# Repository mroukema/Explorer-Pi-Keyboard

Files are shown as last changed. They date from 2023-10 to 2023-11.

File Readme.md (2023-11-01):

# Explorer Pi Keyboard V2

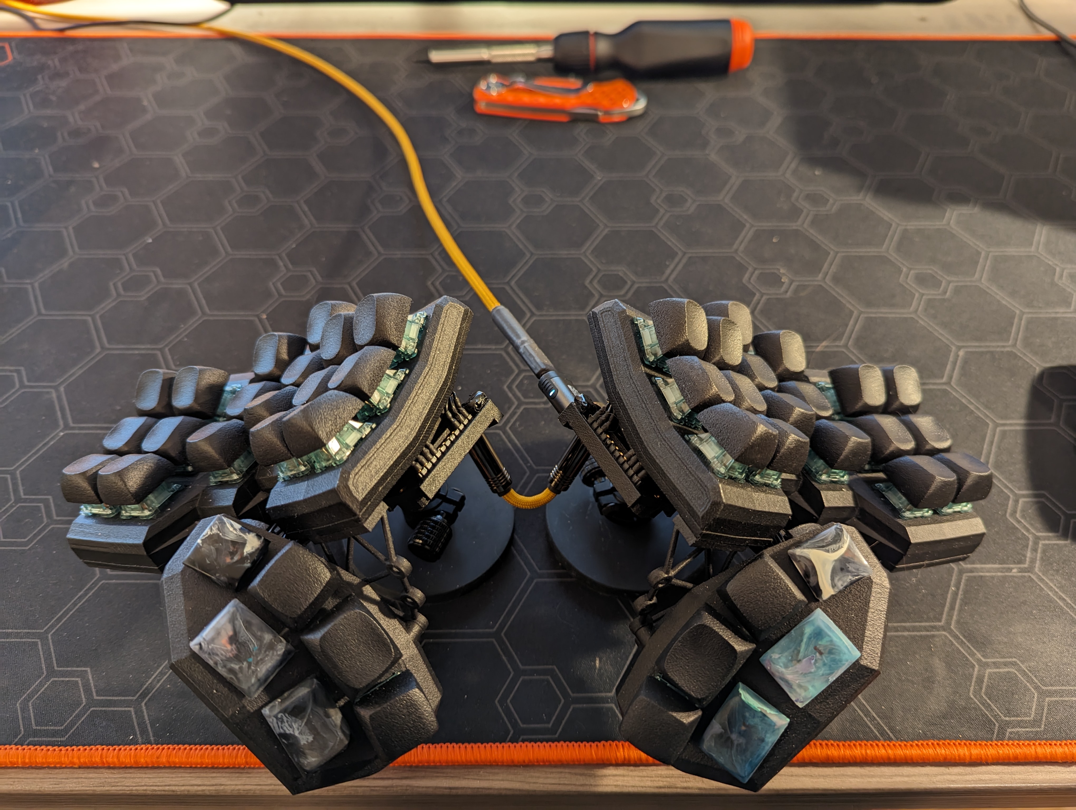
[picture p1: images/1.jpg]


## Introduction 

The Explorer Pi is a customized version of the [Explorer Keyboard RxCT](https://github.com/DreaM117er/Explorer-Keyboard-RxCT/tree/main) designed by [DreaM117er](https://github.com/DreaM117er/). The name comes from the fact that my [original build](https://lemmy.world/post/1733410) of the RxCT was pretty much unmodified aside from using a RP2040 based MCU. 

It's been fitted to my personal ergomomic preferences and some of the originals modualrity has been sacraficed for easier assembly and increased sturdiness. In particular the thumb cluster has been improved with a two piece (top and bottom) design that is much sturdier and has tighter spacing between keys. Additionally any of the thumb cluster keys can be either MX or Choc key switches and this can be changed relatively easily after the fact. 

## Features 
- Thumb cluster with adjustable angles
- MX or choc keyswites an thumb cluster
- Entire thumb cluster is modular (wiring included) and could be easily swapped for a different design
- 1/4" mounting with ARRI locating holes

## Links 

- Explorer PI [QMK Firmware](https://github.com/mroukema/qmk_firmware/tree/explorer_pi_v2/keyboards/explorer_pi/3x6_6) (forked)
- My [Enigma Dual Hot Swap](https://github.com/mroukema/enigma-dual-hs) for thumb cluster keys 
- [Flexible pcb columns](https://skree.us/products/dactyl-compatible-flexible-row-pcbs-populated) by Skree to simplify wiring

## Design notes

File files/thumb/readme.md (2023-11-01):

# Parts
The body of each thumb cluster is made up of a top and bottom half. In addition there is an attachment part to join the thumb cluster to the main keyboard body at an adjustable angle. An optional (but recommended) support strut part is offered in two variation, short and long to further secure the thumb cluster. Finally the mx-spacer is not stictly necessary to use but provides some additional securement for mx keys and a surface to attach pcb to. 

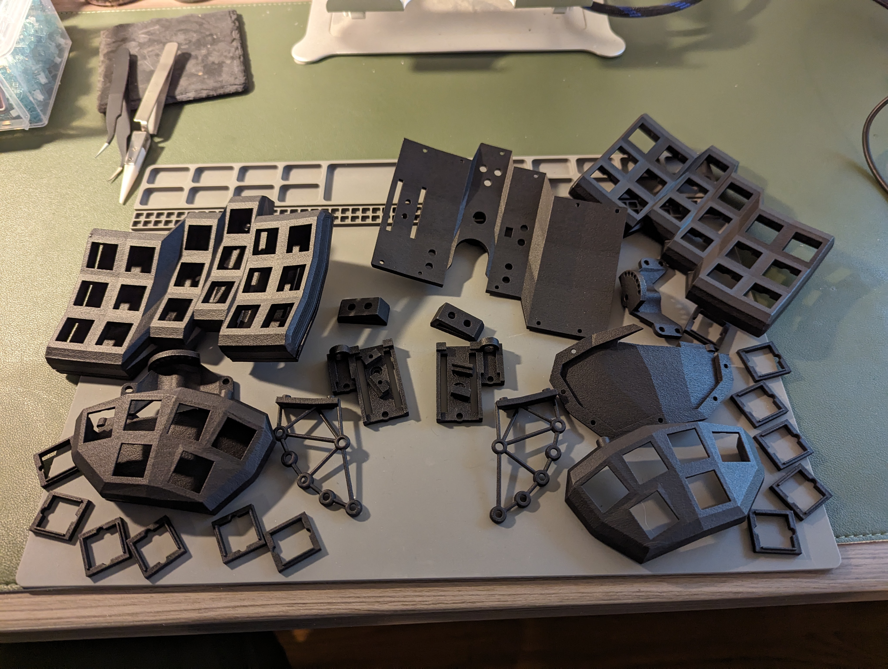
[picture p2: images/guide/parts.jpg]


## Support strut short
Variant of the support sturt compatible with angles between 15-45 degrees.

*note that neither support sturt works with the 0 degree position. As designed the screw position required at 0 degrees overlaps with area where the case meets the top of the strut. 
## Support strut long
Variant of the support sturt compatible with angles between 15-75 degrees.

*note that this still isn't long enough to support the 90 degreee position; it simply seemed to extreme an angle and the part already allows for more rotation than I'll ever use.

## Thumb Attachment 
Part that joins the thumb cluster and main keyboard body together. Allows for angle of attachment to be set between 0-90 degrees in 15 degree increments.

## Thumb Bottom 
Connects to Thumb Attachment via one M2, one M3 screws/threaded insert, and to top via six M2 screws/inserts. Went kinda overboard with threaded attachment points; not all these are sticty needed to be secure, could easily get away with using just three or two. 

## Thumb Top
Connects to Support strut via M3 screws/threaded insert. Switch plate allows for either MX or Choc switches.

Of possible interest might be my [Enigma Dual Hot Swap](https://github.com/mroukema/enigma-dual-hs) single key pcb.

## MX Spacer
Not required but useful for adapting the swich plate height and to provied a surface to glue a pcb to if you wish to be able to hot swap switches with zero disassembly. 

If outsourcing your 3D printing you may find that these end up being priced as the minumum unit cost, meaning you are mostly paying for handing fees not the actual printing. It would be best to batch a bunch of these together by a connecting them with thin bridge and cut them away later. 

TODO: add batched mx spacer file

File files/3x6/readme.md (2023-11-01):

# Parts
The main body of the keyboard is made up of a top and bottom half for each keyboard half. There are two variations on the bottom half explained below; choose one.



## Case Bottom Default
This default version of the bottom half of the case has the 1/4" mounting point in the same position as the V1 model; it's centered on the middle finger column. 

This version also has the holes required to attach both the battery and front mount accessory parts. 

## Case Bottom Offset (still untested)
The offset version of the bottom half of the case has the 1/4" mounting hole shifted down and toward the pinky column. This (hopefully) shifts the center of balance enough to allow for typing without tipping on a ~2.5" dia stand.  

This version does not have any holes for battery of front mount accessory parts. 

## Case Top

Top of case and MX switch plate.

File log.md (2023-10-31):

# Development log

## Updates

- 2023.11.31 adding in bulk all the files that make up my personal V2 of the Explorer keyboard. Changes include 
    - adjusted stagger of each column
    - adjusted splay and height on the pinky columns
    - made the switch plate one piece 
    - added side walls to the switch plate for full enclosure
    - added additional support to the thumb cluster so it has less wobble
    - two piece thumb cluster makes it sturdier and more compact for tighter keyswitch spacing 
    - 6 key thumb cluster
    - support for both choc and mx switches on thumb cluster with swappablity
    - added ARRI locating holes to the 1/4" mounting point
    - added an alternate base plate with modified 1/4" mounting point location for better center of balance
    - reduced total count of required inserts and screws 
    - reduced diameter of the 1/4" insert hole to better fit the inserts I was able to source

## V3/Future potential changes  

- Reduce thickness of trrs mount to for better cable compatabilty 
- fully encluse the mcu 
- move mcu to other side of board
    - trrs should remain on current side, wiring considerations required 
- improve wiring with mating machine pins on top and bottom half
- trackball/trackpoint module
- screen module 
- WiFi based wireless impl
- Reduce MCU assembly part count and improve general design

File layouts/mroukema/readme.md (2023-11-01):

# Layout

Personal layout reference, generated by [Keyboard Layout Editor](http://www.keyboard-layout-editor.com/#/gists/f90687ef3c709af049c13a0a4d5b263d)

Firmware: [Explorer PI QMK Firmware (fork)](https://github.com/mroukema/qmk_firmware/tree/explorer_pi_v2/keyboards/explorer_pi/3x6_6)

## Idle Timeout

Layout features an idle timeout feature that will return the keyboard to the default layer, in this case RSHTD. This will trigger if on any non-default layer and `TIMEOUT_TO_DEFAULT_LAYER` ms have elapsed since last keyboard input. This feature is disabled if `TIMEOUT_TO_DEFAULT_LAYER` is undefined.

```C
#define TIMEOUT_TO_DEFAULT_LAYER 1000 * 60 * 3 // 3mins
```

## Combos

All combos evaluated relative to RSTHD layer regardless of acive layer as a result of below option being used:

```C
#define COMBO_ONLY_FROM_LAYER 0
```

- Alt + C               = TAB
- Alt + S               = ESC
- O + U                 = "OU"
- Q + U                 = "QU"
- Left + Right Shift    = Momentary System Layer
- Num + Sym             = Momentary System Layer
- Swap Hands + Shift    = Momentary System Layer
- Cmd + Minus           = Return to RSTHD Layer
  
## RSTHD (default)

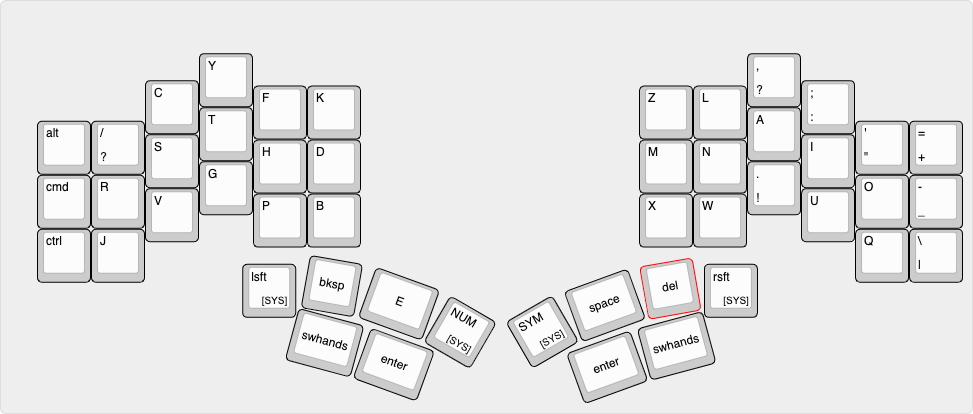
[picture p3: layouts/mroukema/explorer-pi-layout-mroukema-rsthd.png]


## Numpad

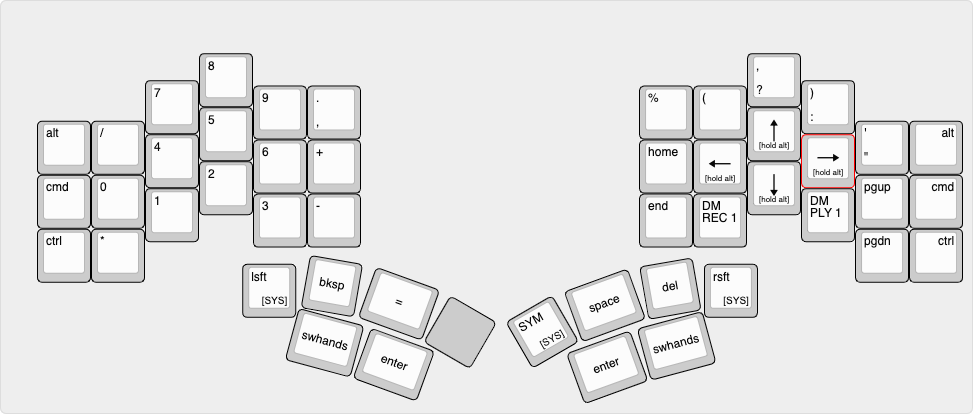
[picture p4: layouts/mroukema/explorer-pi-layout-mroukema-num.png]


## Symbol 

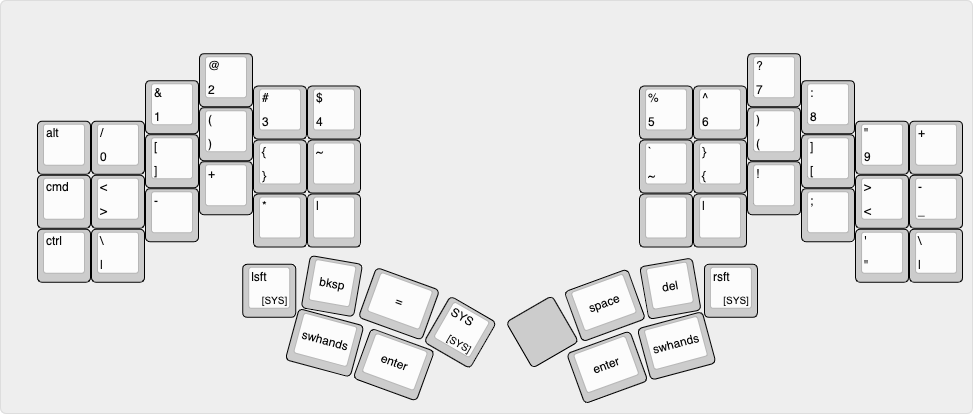
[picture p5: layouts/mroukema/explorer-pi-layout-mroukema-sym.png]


## System

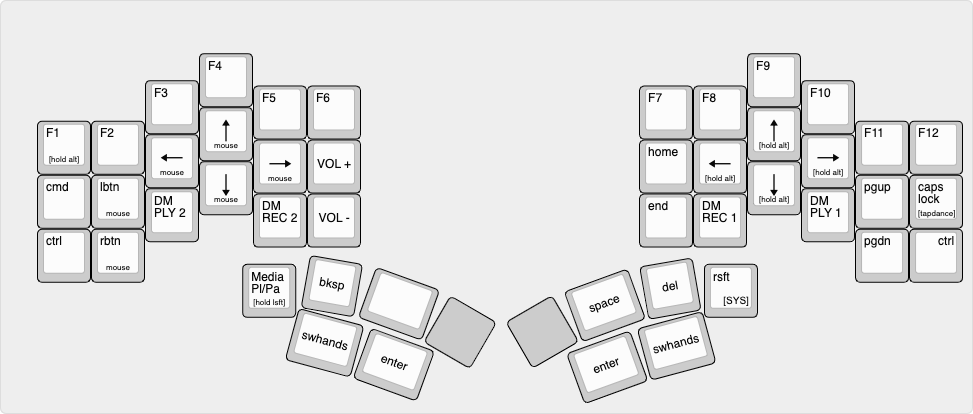
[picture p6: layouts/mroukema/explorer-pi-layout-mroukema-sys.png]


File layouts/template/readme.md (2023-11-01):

# Files

## explorer-pi-layout-template.json

This json is for [Keyboard Layout Editor](http://www.keyboard-layout-editor.com/#/gists/f90687ef3c709af049c13a0a4d5b263d) and is meant to serve as a starting point for your own layer reference. 

## explorer-pi-layout-template.png 
Example of what the editor will generate given template json

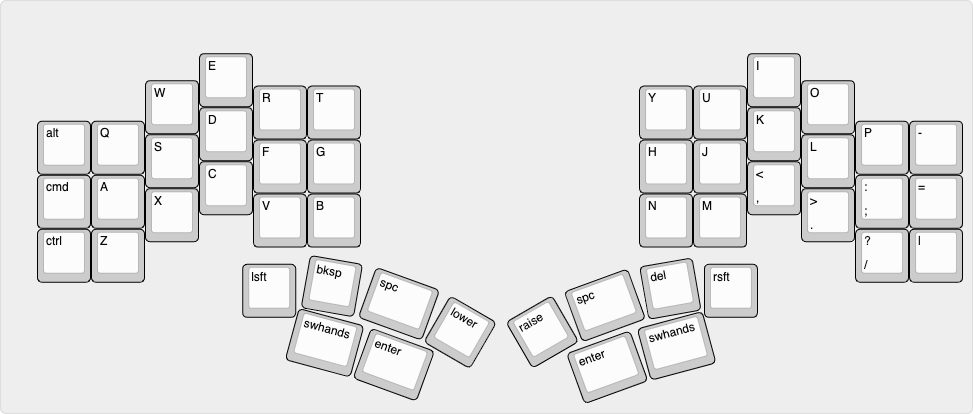
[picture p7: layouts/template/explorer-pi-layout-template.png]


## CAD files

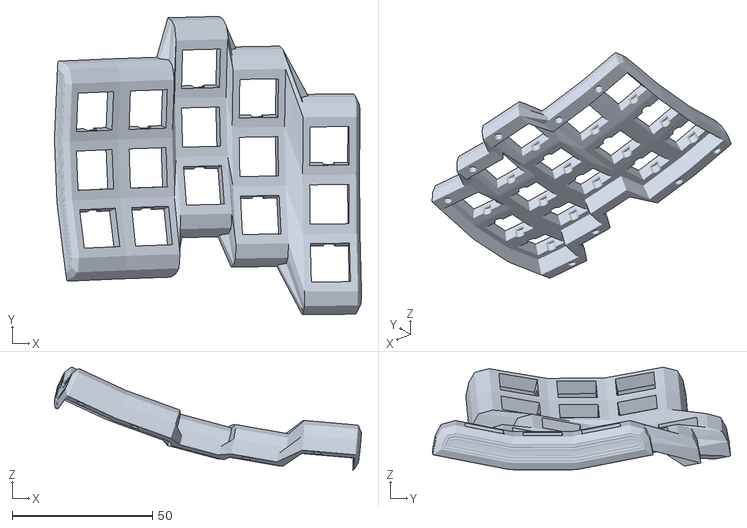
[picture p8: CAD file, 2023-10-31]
files/3x5/right-case-top-3x5.stl
109.6 x 106.4 x 36.6

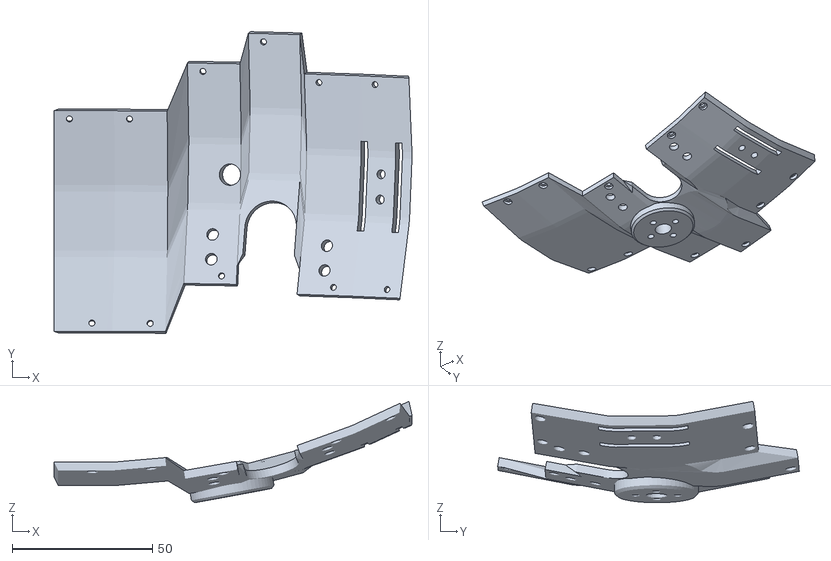
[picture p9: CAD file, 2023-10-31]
files/3x6/left-case-bottom-offset.stl
127.8 x 107.7 x 36.2

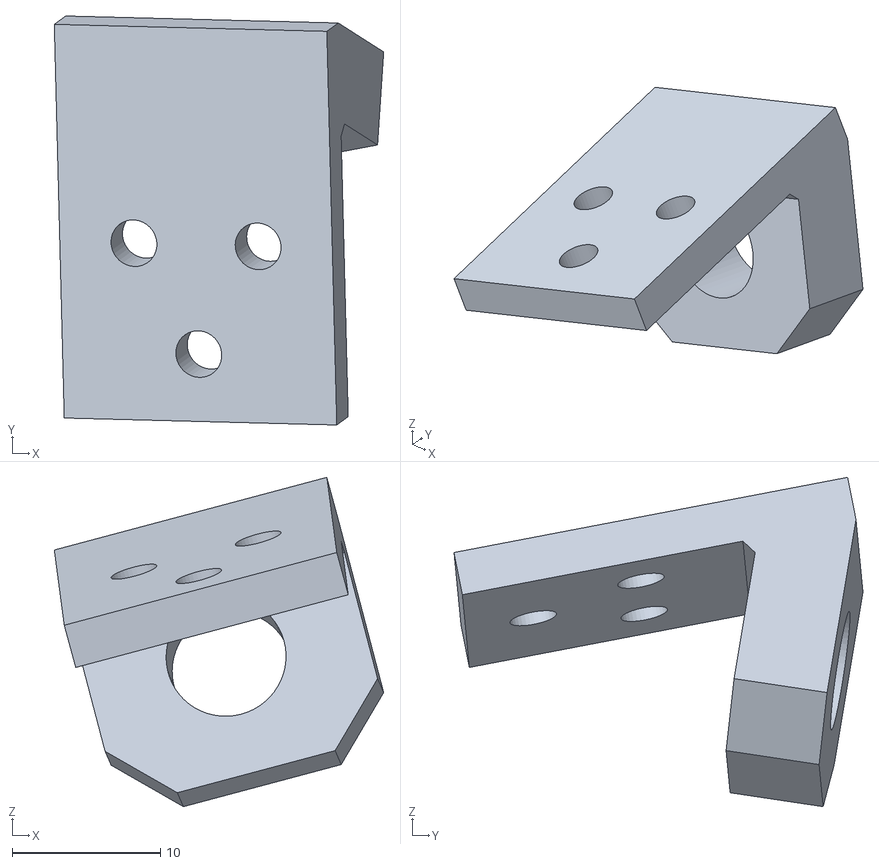
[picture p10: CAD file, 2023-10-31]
files/front-mount.stl
22.2 x 27.6 x 22.2

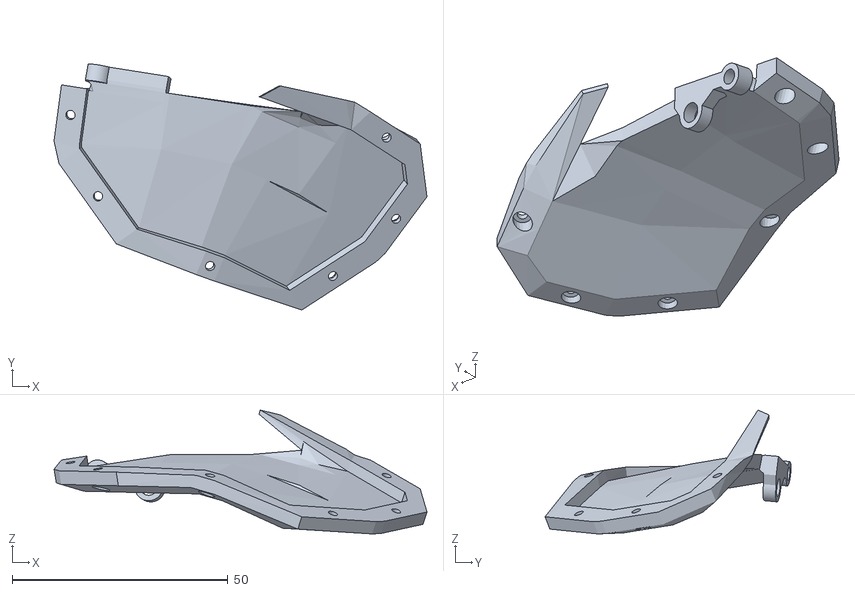
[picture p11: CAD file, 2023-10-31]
files/thumb/left-thumb-bottom.stl
86.4 x 57.0 x 28.7

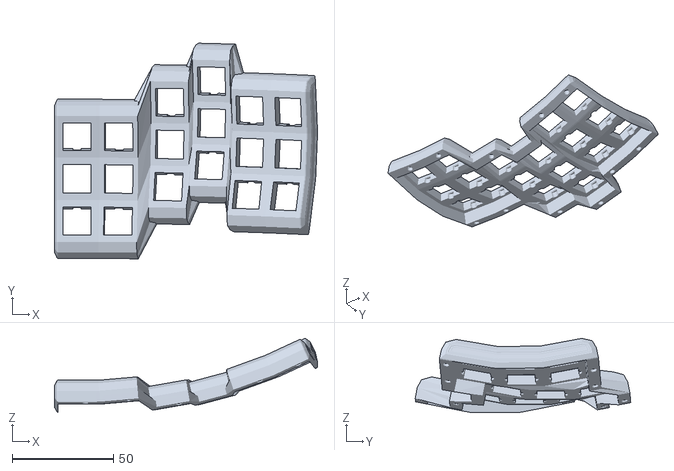
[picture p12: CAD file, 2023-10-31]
files/3x6/left-case-top.stl
129.8 x 106.4 x 36.7

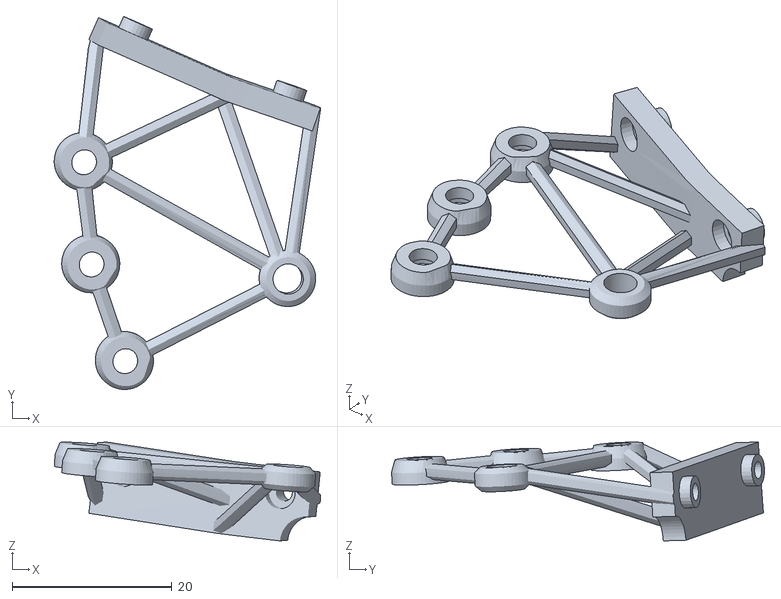
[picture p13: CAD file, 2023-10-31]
files/thumb/right-support-strut-short.stl
33.4 x 46.7 x 12.4

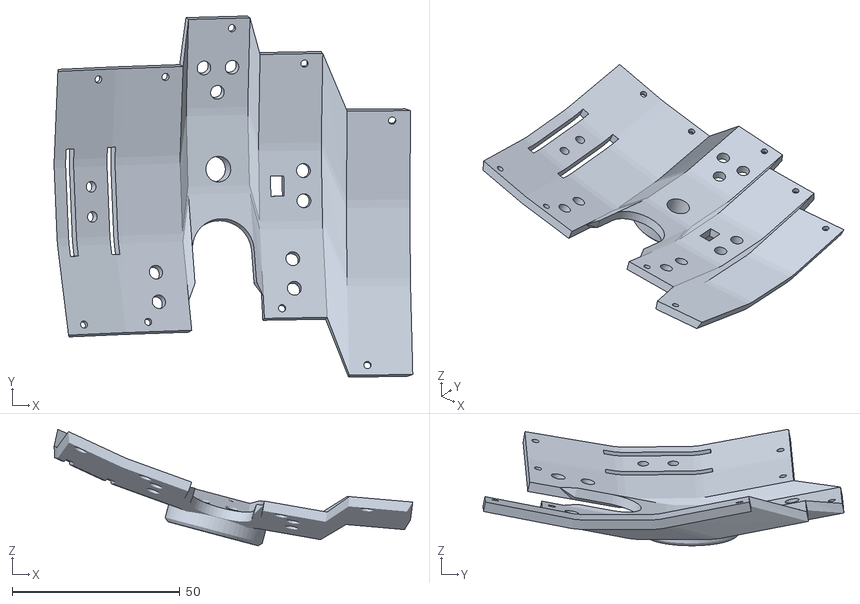
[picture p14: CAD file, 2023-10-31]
files/3x5/right-case-bottom-3x5.stl
107.0 x 107.7 x 34.8

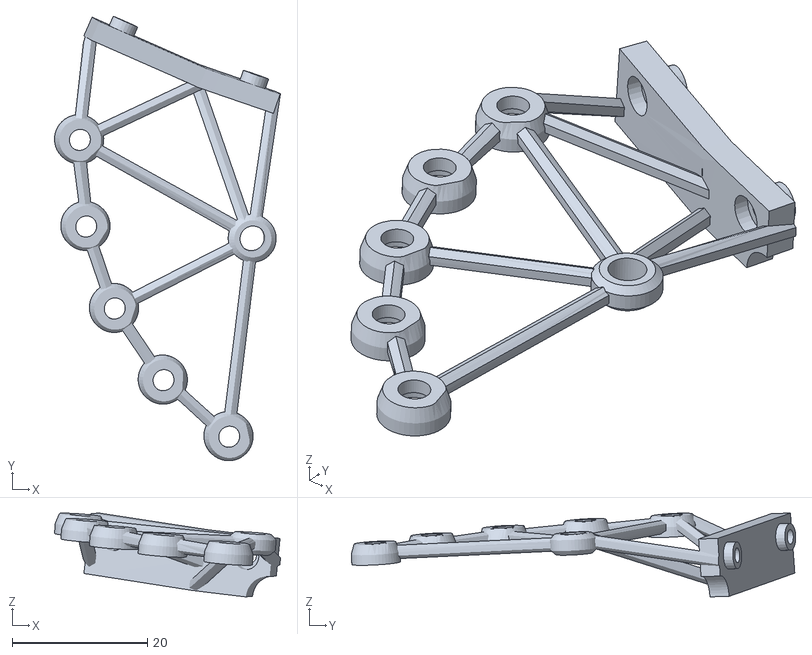
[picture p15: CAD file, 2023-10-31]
files/thumb/right-support-strut-long.stl
33.4 x 65.7 x 12.4

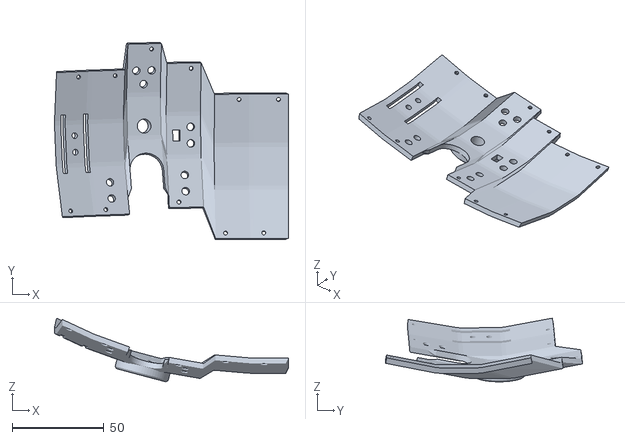
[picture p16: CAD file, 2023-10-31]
files/3x6/right-case-bottom-default.stl
127.8 x 107.7 x 34.8

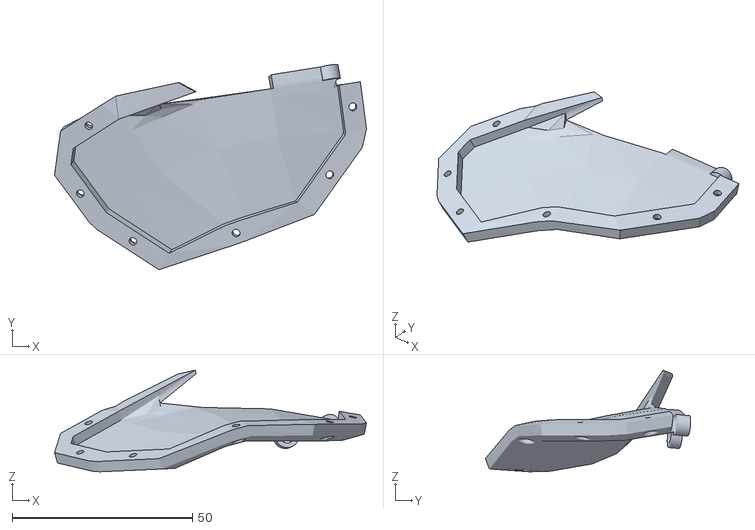
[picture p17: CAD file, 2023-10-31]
files/thumb/right-thumb-bottom.stl
86.5 x 57.0 x 28.2

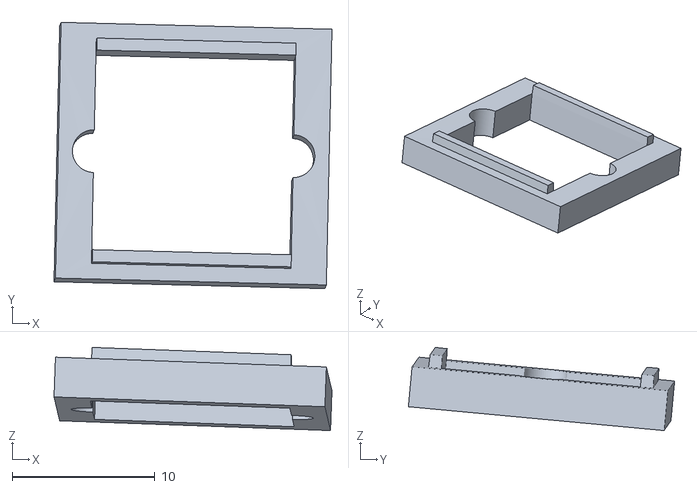
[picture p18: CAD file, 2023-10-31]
files/thumb/mx-spacer.stl
19.5 x 18.7 x 5.83

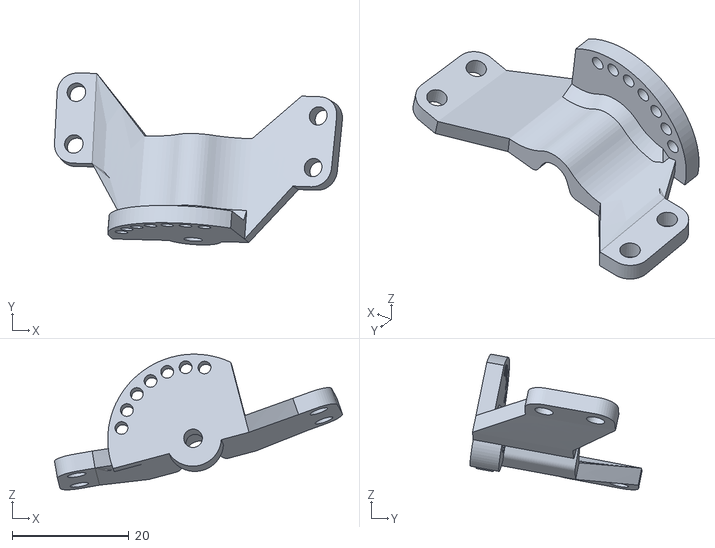
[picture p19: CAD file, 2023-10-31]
files/thumb/left-thumb-attachment.stl
49.2 x 29.4 x 23.2

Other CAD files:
files/3x5/left-case-top-3x5.stl
files/3x6/right-case-bottom-offset.stl
files/thumb/left-support-strut-short.stl
files/3x5/left-case-bottom-3x5.stl
files/3x6/right-case-top.stl
files/3x6/left-case-bottom-default.stl
files/thumb/left-support-sturt-long.stl
files/thumb/left-thumb-top.stl
files/thumb/right-thumb-attachment.stl
files/thumb/right-thumb-top.stl

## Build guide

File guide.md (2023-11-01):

# Build Guide

TBD with V3

## Build Tips

- The desired thumb cluster angle needs to be set before final assembly. Adjusting after the fact is achivable with some difficulty without assembly or by detaching the thumb cluster attachement from the base, though depending on how you have wired things this may be more or less difficult
  - You could leave out the M2 screw that sets the angle on attachement point and rely on the strut to provide a second point of attachement if you wish. It will be less secure but let you adjust the thumb cluster angle with ease.
- Don't wire direct from mcu to the keys. Wire from the mcu to a manifold/male-female extension attached to the base. Then attach from manifold to top/thumb cluster, preferably in a detachable/reattachable manner. I use machine pins and silicone wire to create custom cables.
- Use flexible silicone with 28 or 30 awg wire, especilly in any connections thas will run between detachable parts. Using non-flexible wire will make assembly a pain and prone to breaking. Ask me how I know. 
- [Flexible pcb columns](https://skree.us/products/dactyl-compatible-flexible-row-pcbs-populated) can help simply your build if you are willing to pay for them. I've tested these ones from Skree for compatablity. 

## Pictures


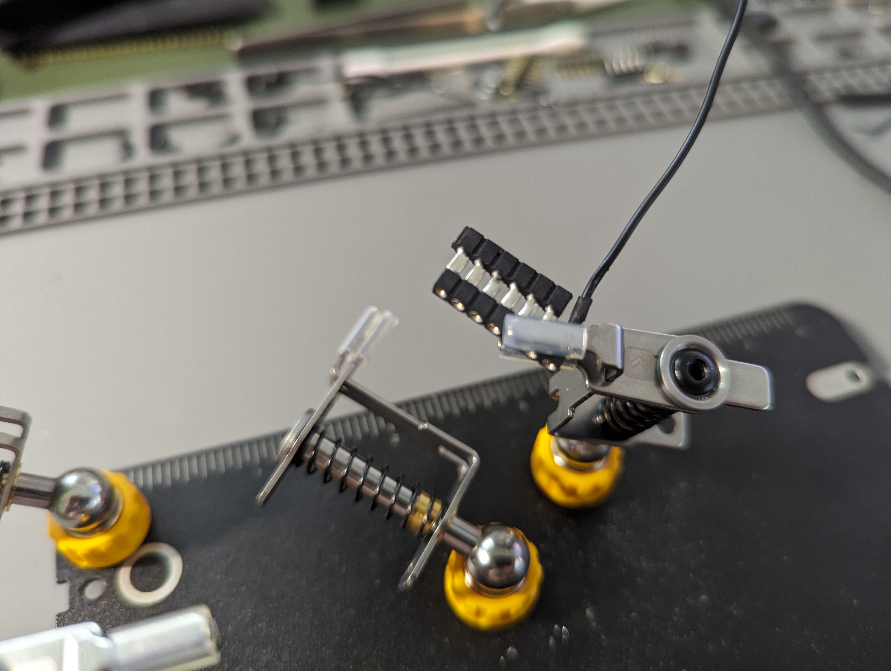
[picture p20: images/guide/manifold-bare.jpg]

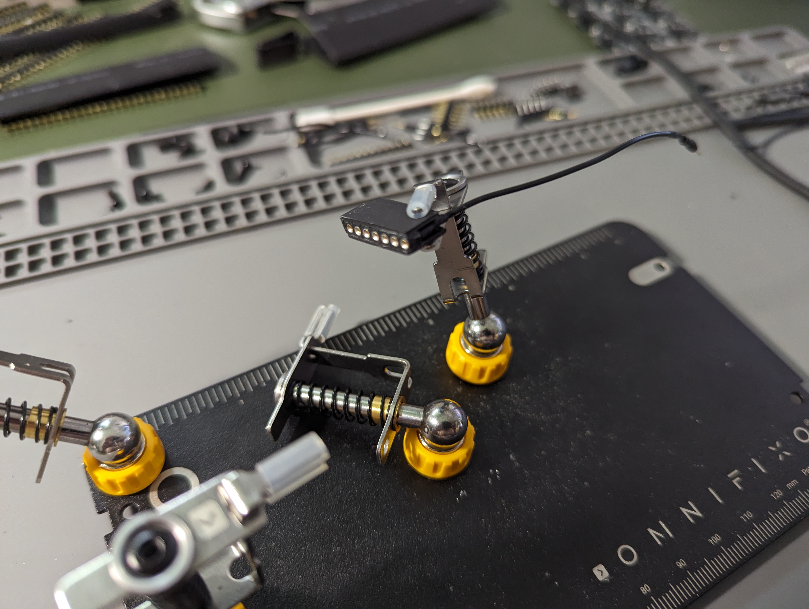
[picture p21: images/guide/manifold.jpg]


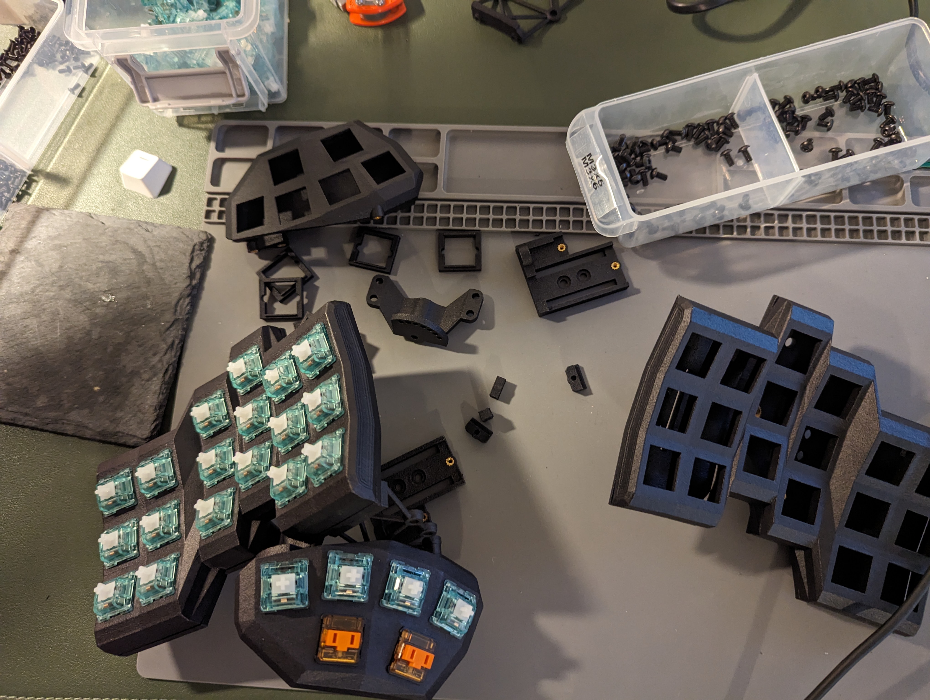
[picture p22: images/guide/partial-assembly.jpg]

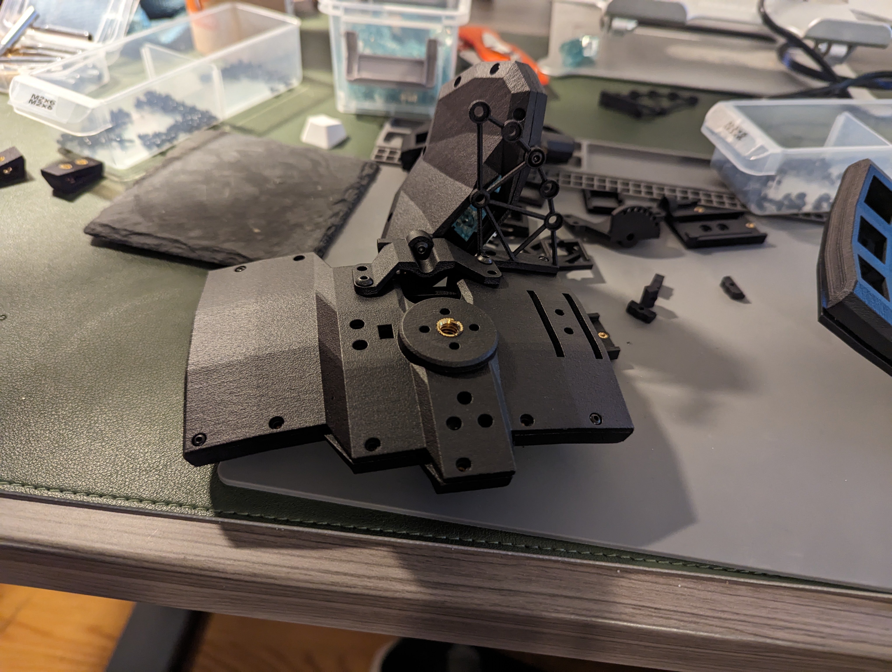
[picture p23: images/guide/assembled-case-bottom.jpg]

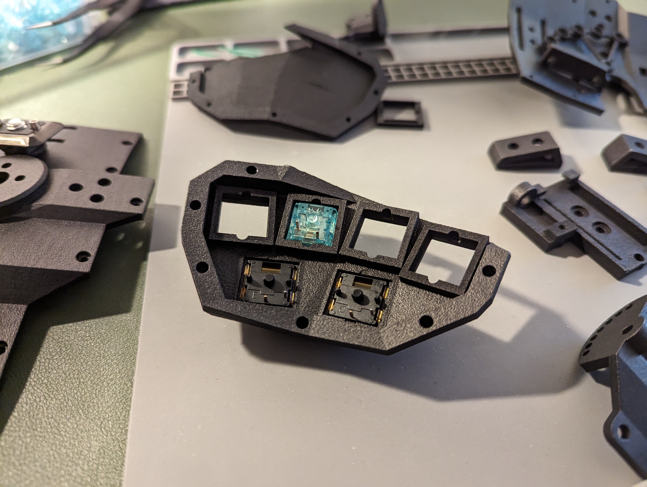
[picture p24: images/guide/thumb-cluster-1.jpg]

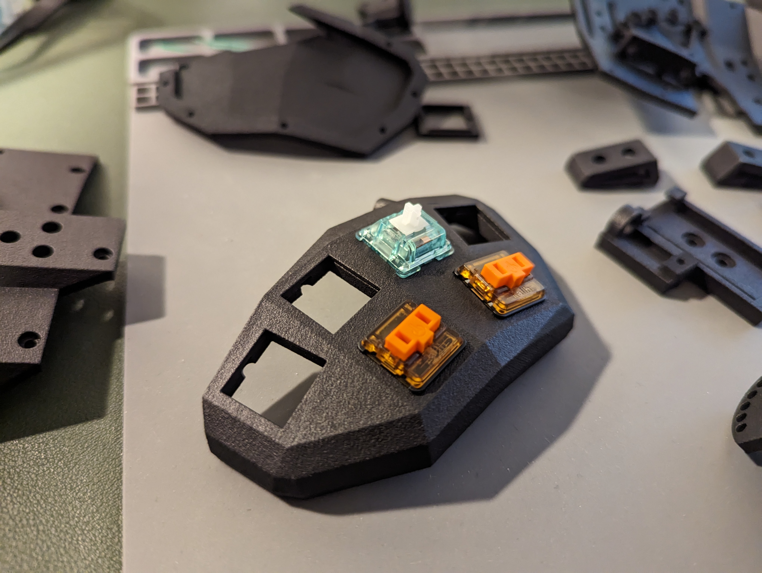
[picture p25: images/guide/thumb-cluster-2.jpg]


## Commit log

2023-10-31 remove obsolete parts
    [3x1-column.stl, 4x1-column.stl, left-3x1 bottom expand case.stl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]
2023-10-31 add updated parts
    [MX-ADAPTER-V2.stl, left-case-bottom-default.stl, left-case-bottom-offset.stl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]
2023-10-31 remame file
    [mx-spacer.stl]
2023-10-31 add 3x5 version of case
    [left-case-bottom-3x5.stl, left-case-top-3x5.stl, right-case-bottom-3x5.stl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]
2023-10-31 update to correct model
    [left-thumb-bottom.stl]
2023-10-31 swap models for long/short left strut
    [left-support-strut-short.stl, left-support-sturt-long.stl]
2023-11-01 remove L/R front mount parts and have just one common part
    [front-mount.stl, right-front-mount.stl]
